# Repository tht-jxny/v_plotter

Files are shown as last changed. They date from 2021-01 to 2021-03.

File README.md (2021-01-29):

# Vertical Plotter
A V-plotter for whiteboards controlled by a WEMOS D1 ESP32.

### Components
For a vertical plotter two motors placed in the top left and right corner move around a pen using tooth belts. A servo motor is used to lift the pen from the surface. An ESP32 is used to control everything. To display debugging messages and to give status updates a simple I2C OLED display is used. The motors cannot be directly connected to the microcontoller as they would get damaged immediately. So one needs an addition motor driver board for each motor. 

- [Servo motor](https://www.amazon.de/meerkleurige-Dupont-stekker-Breadboard-Arduino/dp/B07FQBZ34J/): The simplest solution available
- [Display](https://www.amazon.de/AZDelivery-Display-Arduino-Raspberry-Gratis/dp/B07FYG8MZN/): state of the art
- [Stepper Motor](https://www.amazon.de/STEPPERONLINE-Schrittmotor-63-74oz-4-Draht-Stepper/dp/B07KZL4XCL) along with [Tooth Belt](https://www.amazon.de/ARCELI-Rasterma%C3%9F-Gummi-Zahnriemen-Aluminium-Zahnscheibe-3D-Drucker/dp/B07QH94G71/): Standard NEMA 17 Motor
- [Motor Driver Board](https://www.amazon.de/UEETEK-DRV8825-Schrittmotor-K%C3%BChlk%C3%B6rper-3D-Drucker/dp/B073VK4YN7/): This was used instead of an A4988 driver board because the DRV8825 can handle a higher current and appeared at the time of purchase as the choice of overall  higher quality.
- [D1 Mini ESP32](https://www.amazon.de/AZDelivery-Bluetooth-Internet-Entwicklungsboard-kompatibel/dp/B08BTRQNB3): Chosen because of its compact form-factor and the WiFi- **and** Bluetooth-module. I was using *fritzing* to create the schematics for the project and unfortunately, only the WEMOS D1 Mini was available as a proper microcontoller. Questions concerning the microcontroller can be asked in the *Issues-Tab*.

### Schematics and PCB
I decided to create a PCB for my application as it is easier to solder all the components together. I started using fritzing for the schematics with this result:
schematics-fritzing

### Structure of this repo
The `/res`-folder contains images and several resources to learn about the components involved.  
The `/freecad`-folder contains 3D models as  `.stl` files. Included are models for the gondola, weight-mounts, motor mounts, a case for the control unit and mounts that go directly onto the whiteboard.  
Everything connected to the firmware is located in the `/firmware`-folder. This includes test scripts to examine if every part works as intended. The `config.h` file must be modified with the parameters of your specific case.

### Assembly

### Possible Future Improvements
##### PCB
- More labels
- Altered Capacitor and 12V plug connectors

#### 3D models
- Motor mount additions
- Move motor axle further away from drawing surface
- Design upper PCB case

### TODO:
- Tidy up repo
- Add pictures and guide
- Develop code

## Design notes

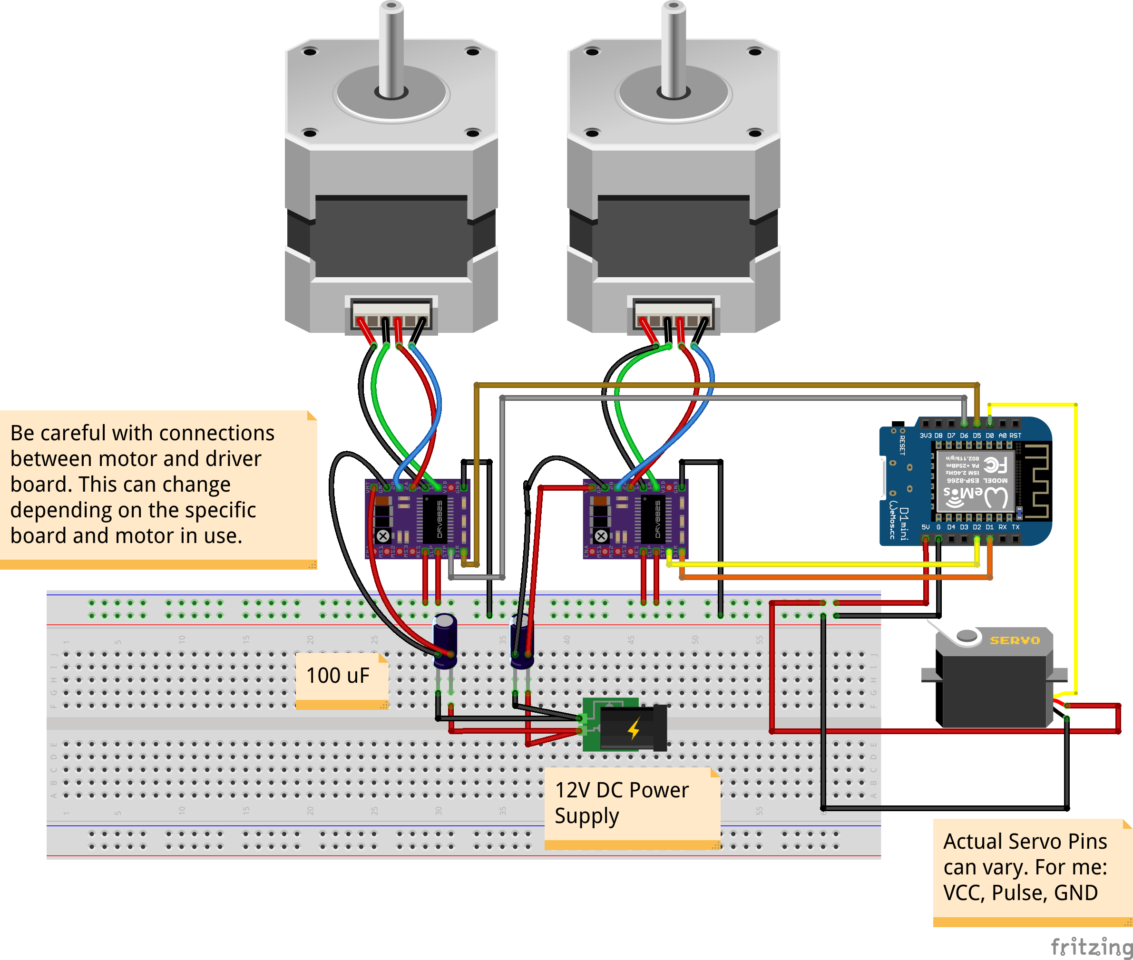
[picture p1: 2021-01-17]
Schematics_and_PCB_Design/v_plotter_v1_bb.png

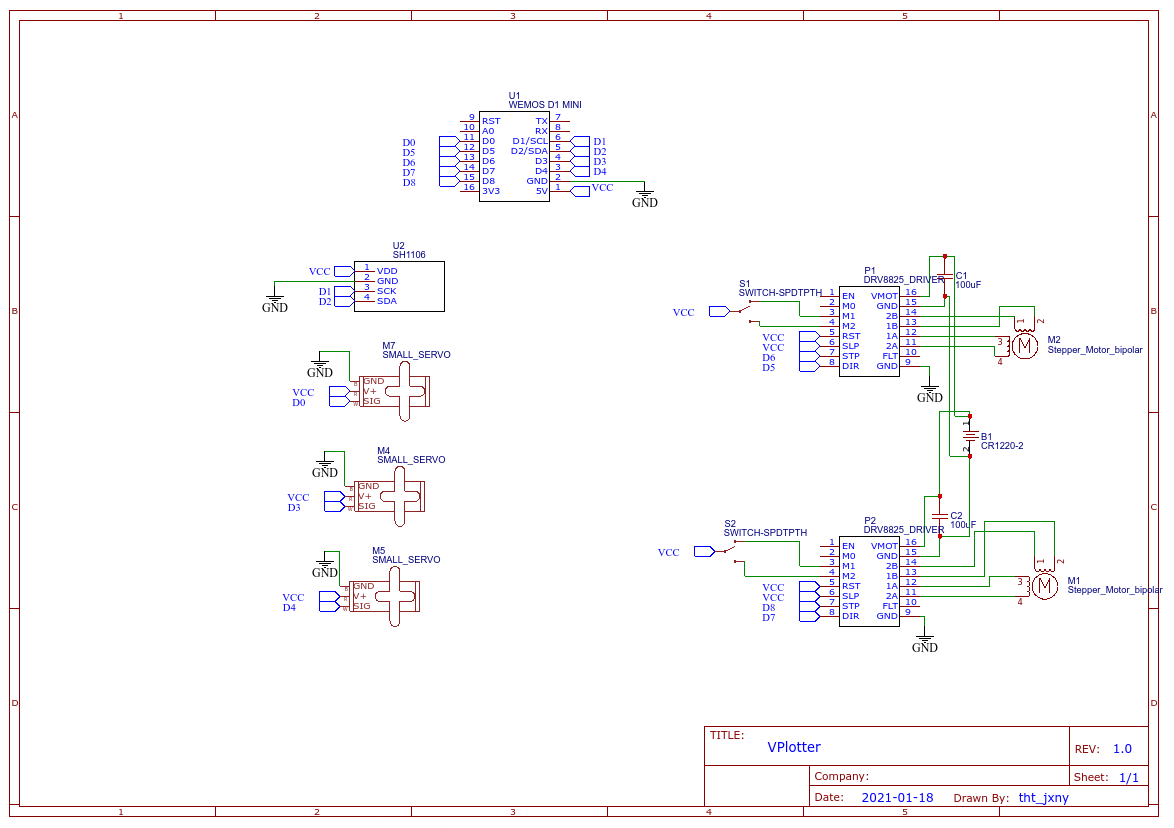
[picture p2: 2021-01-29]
res/Schematic_V_plotter_2021-01-24.png

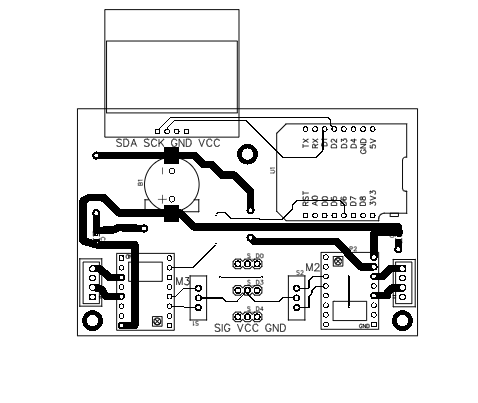
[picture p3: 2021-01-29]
res/PCB_PCB_2021-01-18_21-05-31_2021-01-27.png

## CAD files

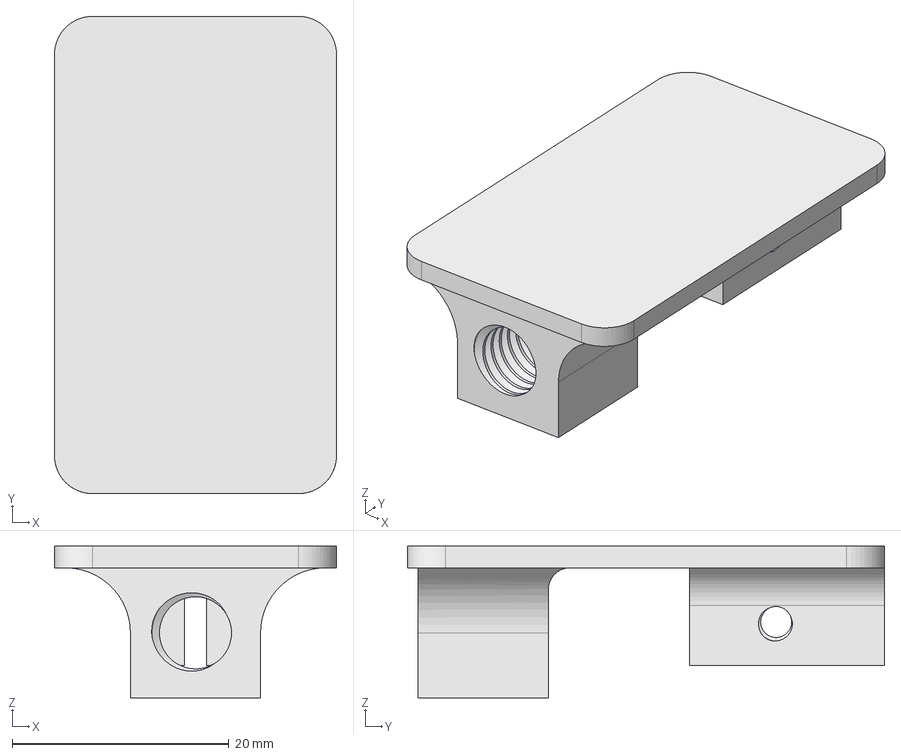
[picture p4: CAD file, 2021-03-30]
FreeCad/Weight.FCStd
26.0 x 44.0 x 14.0 mm

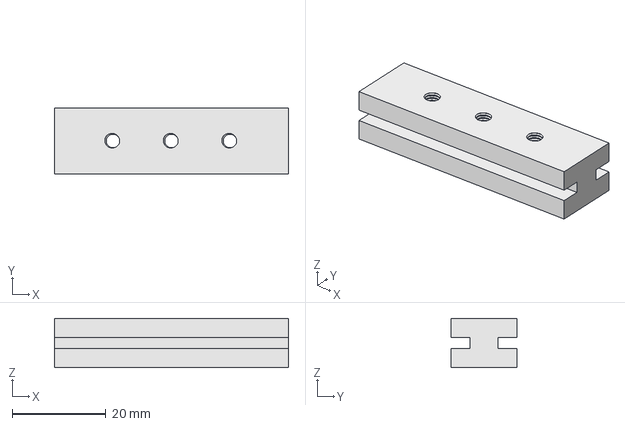
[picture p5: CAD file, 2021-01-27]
FreeCad/Whiteboard_Mount.FCStd
50.0 x 14.0 x 10.5 mm

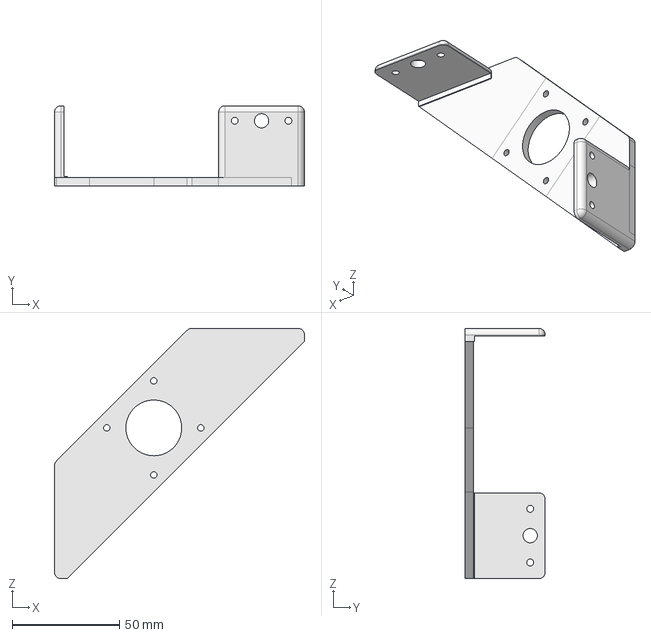
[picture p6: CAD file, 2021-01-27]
FreeCad/Stepper_Motor_Mount.FCStd
116.5 x 37.5 x 116.6 mm

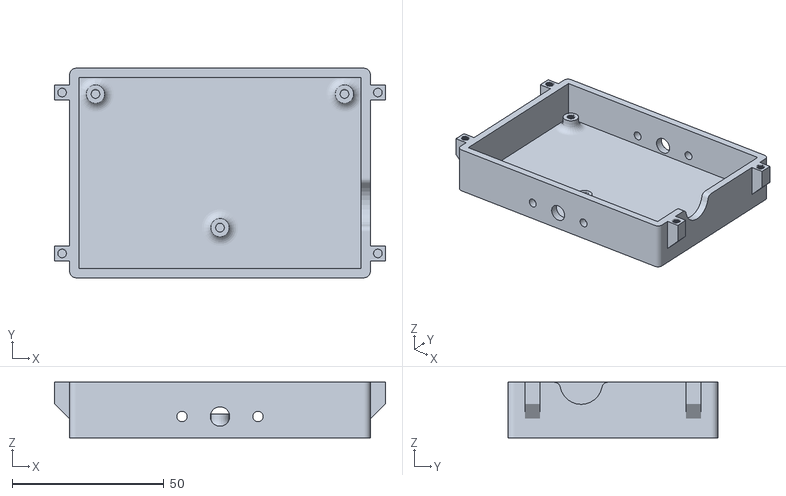
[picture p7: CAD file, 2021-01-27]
FreeCad/PCB_Case_Bottom.stl
109.0 x 69.0 x 18.3

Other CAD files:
FreeCad/PCB_CASE_VPLOTTER.FCStd
FreeCad/PCB_Case.FCStd
FreeCad/Motor_Mount.stl
FreeCad/Weight.stl
FreeCad/Whiteboard_Mount.stl

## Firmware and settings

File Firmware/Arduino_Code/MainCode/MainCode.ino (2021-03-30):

#include <ESP32Servo.h>
#include "config.h"

// Necessary runtime variables:
int current_servo_angle = SERVO_ANGLE_PEN_UP;
float current_left_length = LEFT_STANDARD_LENGTH;
float current_right_length = RIGHT_STANDARD_LENGTH;
float target_left_length = LEFT_STANDARD_LENGTH; // Maybe obsolete
float target_right_length = RIGHT_STANDARD_LENGTH; // Maybe obsolete
int left_addition_factor = 0;
float left_motor_delay = 0;
float right_motor_delay = 0;
float movement_time = 0; // Total time it takes to move
float movement_steps = 0; // Total number of steps to move
int right_addition_factor = 0;


Servo lift_servo; // Creats servo object

void initialize_devices() {
  pinMode(PIN_LEFT_STEP, OUTPUT);
  pinMode(PIN_LEFT_DIR, OUTPUT);
  pinMode(PIN_RIGHT_STEP, OUTPUT);
  pinMode(PIN_RIGHT_DIR, OUTPUT);
  lift_servo.attach(PIN_SERVO);
  lift_servo.write(current_servo_angle);
}

void lift_pen() {
  Serial.println("2");
 current_servo_angle = SERVO_ANGLE_PEN_UP;
 lift_servo.write(SERVO_ANGLE_PEN_UP);
}

void lower_pen() {
  current_servo_angle = SERVO_ANGLE_PEN_DOWN;
  lift_servo.write(SERVO_ANGLE_PEN_DOWN);
}

void calculate_belt_lengths(float x, float y){
  x = x * COORDINATE_SCALE + X_OFFSET;
  y = y * COORDINATE_SCALE + Y_OFFSET;
  target_left_length = sqrt(x*x+y*y);
  target_right_length = sqrt((MOTOR_AXLE_DISTANCE-x)*(MOTOR_AXLE_DISTANCE-x)+y*y);
}

void move_to() {
  Serial.println("3");
  // Draws not outside of canvas
  if ((target_left_length < (sqrt(CANVAS_WIDHT*CANVAS_WIDHT+CANVAS_HEIGHT*CANVAS_HEIGHT)+LEFT_STANDARD_LENGTH)) and (target_right_length < (sqrt(CANVAS_WIDHT*CANVAS_WIDHT+CANVAS_HEIGHT*CANVAS_HEIGHT)+RIGHT_STANDARD_LENGTH))){ 
    float left_travel_distance = target_left_length - current_left_length;
    float right_travel_distance = target_right_length - current_right_length;
    // Set motor directions:
    // Movement for left motor (cw means decreasing length of tooth belt):
    if (left_travel_distance < 0) {
      digitalWrite(PIN_LEFT_DIR, HIGH); // motor direction cw
      left_addition_factor = -1;
    } else {
      digitalWrite(PIN_LEFT_DIR, LOW); // motor direction ccw
      left_addition_factor = 1;
    }
    // Movement for right motor (cw means increasing length of tooth belt):
    if (target_right_length < 0) {
      digitalWrite(PIN_RIGHT_DIR, LOW); // motor direction ccw
      right_addition_factor = -1;
    } else{
      digitalWrite(PIN_RIGHT_DIR, HIGH); // motor direction cw 
      right_addition_factor = 1;
    }
     // Calculate motor delays; Motor with longer distance has to move faster (v_max)
     // Check which motor has to move further:
     if (abs(left_travel_distance) > abs(right_travel_distance)){ // Left motor has to move faster; Keep in mind: speed = distance / time
        movement_time = left_travel_distance / V_MAX;
        movement_steps = left_travel_distance * STEP_DISTANCE;
        left_motor_delay = movement_time/movement_steps; // In seconds; delay = time/steps = (steps/speed)/steps = 1/speed
        float other_motor_speed = right_travel_distance / movement_time; // In mm/s
        right_motor_delay = 1 / (other_motor_speed * STEP_DISTANCE);
        // Chance unit of delays from seconds to microseconds:
        left_motor_delay *= 1000000;
        right_motor_delay *= 1000000;
     } else{ // Right motor has to move faster
        movement_time = right_travel_distance / V_MAX;
        movement_steps = right_travel_distance * STEP_DISTANCE;
        right_motor_delay = movement_time/movement_steps; // In seconds; delay = time/steps = (steps/speed)/steps = 1/speed
        float other_motor_speed = left_travel_distance / movement_time; // In mm/s
        left_motor_delay = 1 / (other_motor_speed * STEP_DISTANCE);
        // Chance unit of delays from seconds to microseconds:
        //left_motor_delay *= 1000000;
        //right_motor_delay *= 1000000;
     }
    Serial.println("1");
    Serial.println(movement_steps);
    // Spin motors the right amount of time: 
    for (int i = 0; i < int(abs(movement_steps)); i++){
      digitalWrite(PIN_LEFT_STEP, HIGH);
      delayMicroseconds(abs(left_motor_delay));
      digitalWrite(PIN_LEFT_STEP, LOW);
      digitalWrite(PIN_RIGHT_STEP, HIGH);
      delayMicroseconds(abs(right_motor_delay));
      digitalWrite(PIN_RIGHT_STEP, LOW);
      
    }
    current_right_length = target_right_length;
    current_left_length = target_left_length;
    Serial.println("Moved to desired location!");
  }
}

void move_to_origin() {
  calculate_belt_lengths(0,0);
  move_to();
}


                  
void setup() {
  Serial.begin(115200);
  initialize_devices();
}


void loop() {
  Serial.println("moving pen");
  lift_pen();
  delay(2000);
  lower_pen();
  delay(2000);
  // Moving means calculating the belt lengths to reach; then determining the speed / delay of each motor; then spin motors
  // Speed of motors differ because they have to finish the move at the same time -> Create a line 
  calculate_belt_lengths(100,  100);
  move_to();
  delay(2000);
  calculate_belt_lengths(100, 50);
  move_to();
  delay(2000);
  calculate_belt_lengths(50, 100);
  move_to();
  delay(2000);
  move_to_origin();
  delay(2000);
}


  

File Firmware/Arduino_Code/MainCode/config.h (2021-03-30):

#ifndef H_CONFIG
#define H_CONFIG

#include <Arduino.h>

// GPIO numbers where the components are connected:
const int PIN_LEFT_STEP = 5;
const int PIN_LEFT_DIR = 23;
const int PIN_RIGHT_STEP = 19;
const int PIN_RIGHT_DIR = 18;
const int PIN_SERVO = 26;

// Possible servo positions/angles:
const int SERVO_ANGLE_PEN_UP = 0;
const int SERVO_ANGLE_PEN_DOWN = 90;


// Number of steps that translate to a 1 mm movement (needs to be measured):
const int STEP_DISTANCE = 108;

// Speed (v_max for plotting process); In my case: 15 mm/s to 25 mm/s is pretty good
const float V_MAX = 20; // Measured in mm/s
const float STEPS_PER_SECOND = V_MAX * STEP_DISTANCE;
// Delay between two motor movements should be >35 for sixteenth step mode; >950 for full step mode

// Scale factor to scale given coordinates:
const int COORDINATE_SCALE = 1;

// Distance between both motor axles in millimetres (needs to be measured):
const int MOTOR_AXLE_DISTANCE = 532;

// Length of both tooth belts in millimetres when in origin position:
const int LEFT_STANDARD_LENGTH = 180;
const int RIGHT_STANDARD_LENGTH = 430;

// Size of canvas in millimetres:
const int CANVAS_WIDHT = 400;
const int CANVAS_HEIGHT = 400;

// Origin has  in truth the following coordinates:
const float X_OFFSET = ((LEFT_STANDARD_LENGTH*LEFT_STANDARD_LENGTH)-(RIGHT_STANDARD_LENGTH*RIGHT_STANDARD_LENGTH)+(MOTOR_AXLE_DISTANCE*MOTOR_AXLE_DISTANCE))/(2*MOTOR_AXLE_DISTANCE);
const float Y_OFFSET = sqrt(LEFT_STANDARD_LENGTH*LEFT_STANDARD_LENGTH-X_OFFSET*X_OFFSET);
#endif // H_CONFIG

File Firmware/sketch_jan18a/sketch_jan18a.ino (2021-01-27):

/**************************************************************************
 This is an example for our Monochrome OLEDs based on SSD1306 drivers
 Pick one up today in the adafruit shop!
 ------> http://www.adafruit.com/category/63_98
 This example is for a 128x64 pixel display using I2C to communicate
 3 pins are required to interface (two I2C and one reset).
 Adafruit invests time and resources providing this open
 source code, please support Adafruit and open-source
 hardware by purchasing products from Adafruit!
 Written by Limor Fried/Ladyada for Adafruit Industries,
 with contributions from the open source community.
 BSD license, check license.txt for more information
 All text above, and the splash screen below must be
 included in any redistribution.
 **************************************************************************/

#include <SPI.h>
#include <Wire.h>
#include <Adafruit_GFX.h>
#include <Adafruit_SSD1306.h>

#define SCREEN_WIDTH 128 // OLED display width, in pixels
#define SCREEN_HEIGHT 64 // OLED display height, in pixels

// Declaration for an SSD1306 display connected to I2C (SDA, SCL pins)
// The pins for I2C are defined by the Wire-library. 
// On an arduino UNO:       A4(SDA), A5(SCL)
// On an arduino MEGA 2560: 20(SDA), 21(SCL)
// On an arduino LEONARDO:   2(SDA),  3(SCL), ...
#define OLED_RESET     4 // Reset pin # (or -1 if sharing Arduino reset pin)
#define SCREEN_ADDRESS 0x3D ///< See datasheet for Address; 0x3D for 128x64, 0x3C for 128x32
Adafruit_SSD1306 display(SCREEN_WIDTH, SCREEN_HEIGHT, &Wire, OLED_RESET);

#define NUMFLAKES     10 // Number of snowflakes in the animation example

#define LOGO_HEIGHT   16
#define LOGO_WIDTH    16
static const unsigned char PROGMEM logo_bmp[] =
{ B00000000, B11000000,
  B00000001, B11000000,
  B00000001, B11000000,
  B00000011, B11100000,
  B11110011, B11100000,
  B11111110, B11111000,
  B01111110, B11111111,
  B00110011, B10011111,
  B00011111, B11111100,
  B00001101, B01110000,
  B00011011, B10100000,
  B00111111, B11100000,
  B00111111, B11110000,
  B01111100, B11110000,
  B01110000, B01110000,
  B00000000, B00110000 };

void setup() {
  Serial.begin(9600);

  // SSD1306_SWITCHCAPVCC = generate display voltage from 3.3V internally
  if(!display.begin(SSD1306_SWITCHCAPVCC, SCREEN_ADDRESS)) {
    Serial.println(F("SSD1306 allocation failed"));
    for(;;); // Don't proceed, loop forever
  }

  // Show initial display buffer contents on the screen --
  // the library initializes this with an Adafruit splash screen.
  display.display();
  delay(2000); // Pause for 2 seconds

  // Clear the buffer
  display.clearDisplay();

  // Draw a single pixel in white
  display.drawPixel(10, 10, SSD1306_WHITE);

  // Show the display buffer on the screen. You MUST call display() after
  // drawing commands to make them visible on screen!
  display.display();
  delay(2000);
  // display.display() is NOT necessary after every single drawing command,
  // unless that's what you want...rather, you can batch up a bunch of
  // drawing operations and then update the screen all at once by calling
  // display.display(). These examples demonstrate both approaches...

  testdrawline();      // Draw many lines

  testdrawrect();      // Draw rectangles (outlines)

  testfillrect();      // Draw rectangles (filled)

  testdrawcircle();    // Draw circles (outlines)

  testfillcircle();    // Draw circles (filled)

  testdrawroundrect(); // Draw rounded rectangles (outlines)

  testfillroundrect(); // Draw rounded rectangles (filled)

  testdrawtriangle();  // Draw triangles (outlines)

  testfilltriangle();  // Draw triangles (filled)

  testdrawchar();      // Draw characters of the default font

  testdrawstyles();    // Draw 'stylized' characters

  testscrolltext();    // Draw scrolling text

  testdrawbitmap();    // Draw a small bitmap image

  // Invert and restore display, pausing in-between
  display.invertDisplay(true);
  delay(1000);
  display.invertDisplay(false);
  delay(1000);

  testanimate(logo_bmp, LOGO_WIDTH, LOGO_HEIGHT); // Animate bitmaps
}

void loop() {
}

void testdrawline() {
  int16_t i;

  display.clearDisplay(); // Clear display buffer

  for(i=0; i<display.width(); i+=4) {
    display.drawLine(0, 0, i, display.height()-1, SSD1306_WHITE);
    display.display(); // Update screen with each newly-drawn line
    delay(1);
  }
  for(i=0; i<display.height(); i+=4) {
    display.drawLine(0, 0, display.width()-1, i, SSD1306_WHITE);
    display.display();
    delay(1);
  }
  delay(250);

  display.clearDisplay();

  for(i=0; i<display.width(); i+=4) {
    display.drawLine(0, display.height()-1, i, 0, SSD1306_WHITE);
    display.display();
    delay(1);
  }
  for(i=display.height()-1; i>=0; i-=4) {
    display.drawLine(0, display.height()-1, display.width()-1, i, SSD1306_WHITE);
    display.display();
    delay(1);
  }
  delay(250);

  display.clearDisplay();

  for(i=display.width()-1; i>=0; i-=4) {
    display.drawLine(display.width()-1, display.height()-1, i, 0, SSD1306_WHITE);
    display.display();
    delay(1);
  }
  for(i=display.height()-1; i>=0; i-=4) {
    display.drawLine(display.width()-1, display.height()-1, 0, i, SSD1306_WHITE);
    display.display();
    delay(1);
  }
  delay(250);

  display.clearDisplay();

  for(i=0; i<display.height(); i+=4) {
    display.drawLine(display.width()-1, 0, 0, i, SSD1306_WHITE);
    display.display();
    delay(1);
  }
  for(i=0; i<display.width(); i+=4) {
    display.drawLine(display.width()-1, 0, i, display.height()-1, SSD1306_WHITE);
    display.display();
    delay(1);
  }

  delay(2000); // Pause for 2 seconds
}

void testdrawrect(void) {
  display.clearDisplay();

  for(int16_t i=0; i<display.height()/2; i+=2) {
    display.drawRect(i, i, display.width()-2*i, display.height()-2*i, SSD1306_WHITE);
    display.display(); // Update screen with each newly-drawn rectangle
    delay(1);
  }

  delay(2000);
}

void testfillrect(void) {
  display.clearDisplay();

  for(int16_t i=0; i<display.height()/2; i+=3) {
    // The INVERSE color is used so rectangles alternate white/black
    display.fillRect(i, i, display.width()-i*2, display.height()-i*2, SSD1306_INVERSE);
    display.display(); // Update screen with each newly-drawn rectangle
    delay(1);
  }

  delay(2000);
}

void testdrawcircle(void) {
  display.clearDisplay();

  for(int16_t i=0; i<max(display.width(),display.height())/2; i+=2) {
    display.drawCircle(display.width()/2, display.height()/2, i, SSD1306_WHITE);
    display.display();
    delay(1);
  }

  delay(2000);
}

void testfillcircle(void) {
  display.clearDisplay();

  for(int16_t i=max(display.width(),display.height())/2; i>0; i-=3) {
    // The INVERSE color is used so circles alternate white/black
    display.fillCircle(display.width() / 2, display.height() / 2, i, SSD1306_INVERSE);
    display.display(); // Update screen with each newly-drawn circle
    delay(1);
  }

  delay(2000);
}
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

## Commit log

2021-01-17 added first version files
    [v_plotter_additional.fzz, v_plotter_v1.fzz]
2021-01-27 Added CAD files
    [Motor_Mount.stl, PCB_CASE_VPLOTTER.FCStd, PCB_Case.FCStd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]
2021-01-29 Added schematics and first batch of code
2021-03-30 updated cad of weight
    [Weight.FCStd, Weight.stl]
